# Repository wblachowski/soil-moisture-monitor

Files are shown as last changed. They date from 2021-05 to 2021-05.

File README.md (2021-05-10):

# Soil Moisture Monitor 🌱
> There's no reason to stick your finger in the dirt ever again.

This is an Arduino project for monitoring soil moisture to keep your plants lush and healthy. It comes with a standard moisture reading as well as automatic watering detection to let you know how long it's been since the last watering.

## Components
Originally, the project uses the following components (albeit many of these could be substituted with their counterparts without much effort):
* Arduino Nano
* LM393 Soil moisture sensor
* DS3231 RTC
* SSD1306 128x32 OLED Display

## Usage
The main aim of the monitor is to display the soil moisture to the user. However, there are a few add-ons to make the experience even better.

### Moisture sensing
The moisture is measured every minute by supplying the power to the sensor for 50ms and taking the measurement. The measurement in 0-100% format is then displayed in large font in the left part fo the display.

The reason for taking measurements at intervals instead of continuously is to slow down the sensor rusting (some rusting can't be prevented, sadly).

### Watering detection
The system measures the Exponential Moving Average of the sensor measurements and keeps track of the latest 30 values.
Based on some thresholds, the monitor detects whether a significant increase in the moisture has occurred.
Once watering is detected, the system saves the watering time in its non-volatile memory and, henceforth, displays the time that has passed since the last watering on the right-hand side of the display.
A new watering can't be detected until at least 3 hours since the last one.
This behaviour aims to prevent multiple watering events from being detected if the moisture level keeps raising for an extended period of time after the actual watering.

### Watering triggering
If the user feels uncertain about the automatic watering detection mechanism, they can let the system know that the watering has happened by pressing a special button and holding it for 2 seconds.
This event is treated in the same way as the automatic detection.

## Structure

* `main`

Contains arduino code.

* `pcb`

Contains designs for a printed circuit board, created in Autodesk EAGLE.

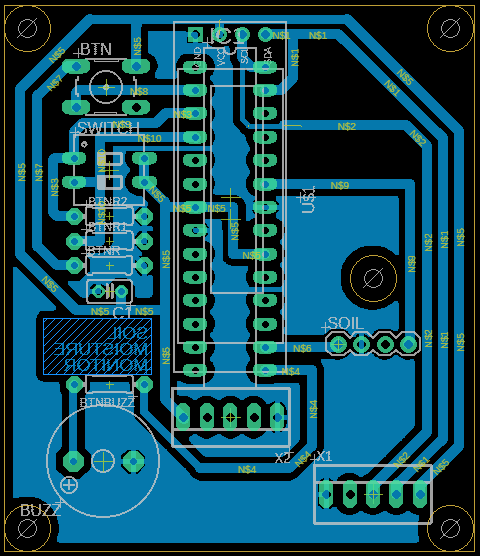
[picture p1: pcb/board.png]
pcb


* `case`

Contains the design of a 3D-printable case for the complete project. The case has snap joints and special cutouts for LCD, power supply, and moisture sensor connection.

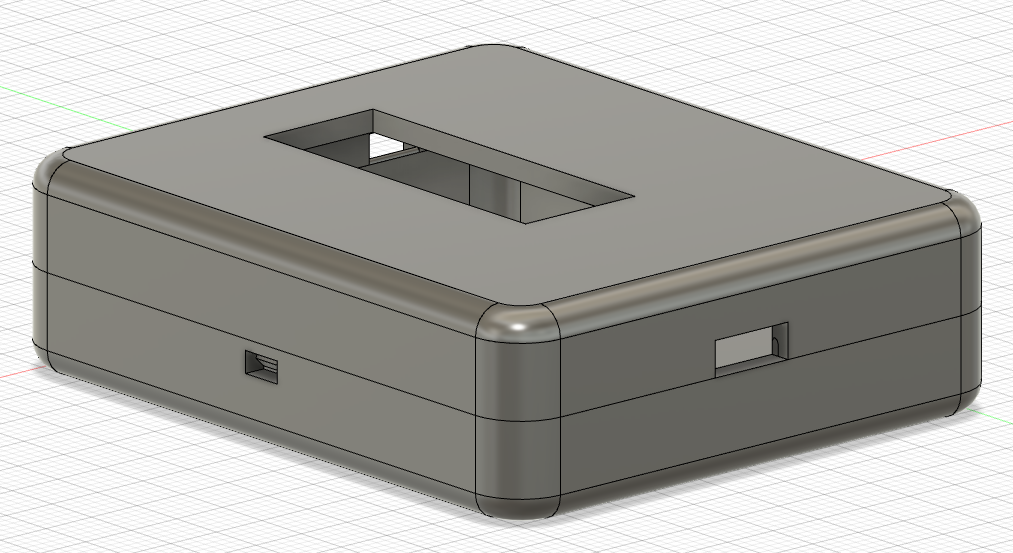
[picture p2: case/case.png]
case


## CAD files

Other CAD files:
case/Moisture monitor case.f3d

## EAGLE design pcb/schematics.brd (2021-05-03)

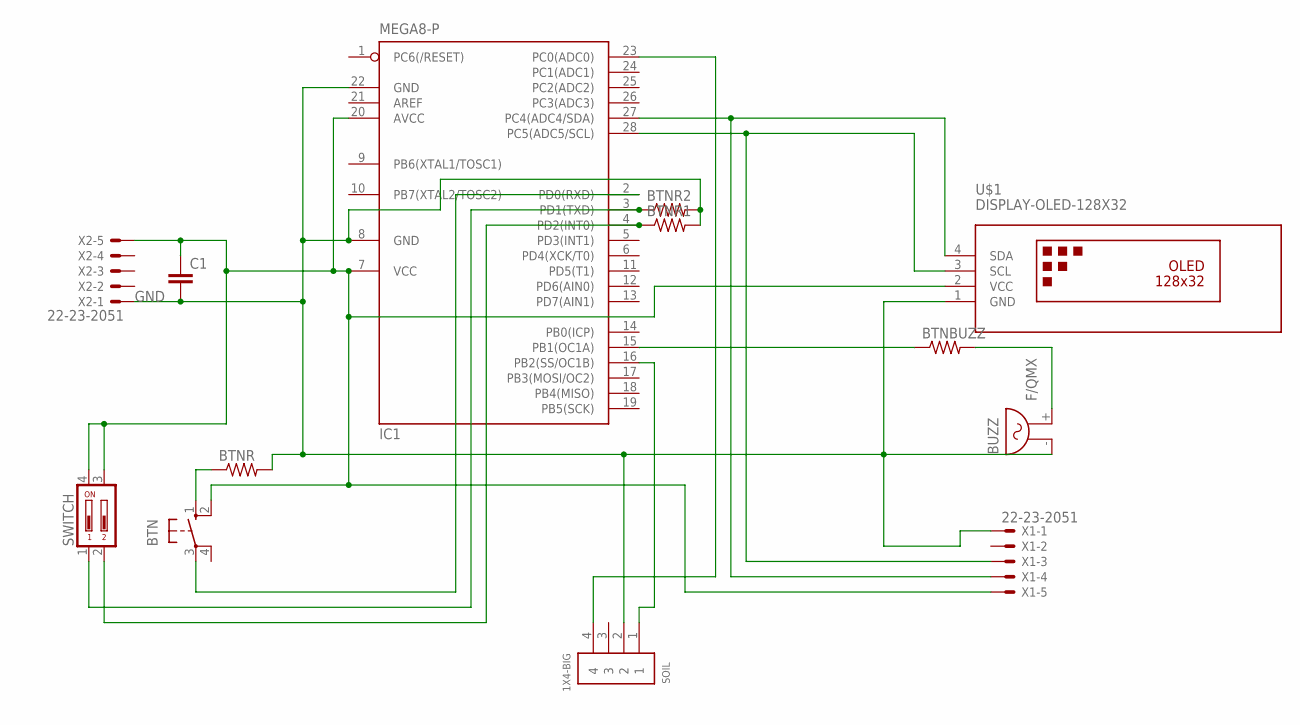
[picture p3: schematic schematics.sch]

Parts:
BTN: 10-XX; B3F-10XX
BTNBUZZ: R-US_0204/7; 0204/7
BTNR, BTNR1, BTNR2: R-US_0204/7; 0204/7
BUZZ: F/QMX
C1: C-EU025-025X050; C025-025X050
IC1: MEGA8-P; DIL28-3
SOIL: 1X4-BIG; 1X04-BIG
SWITCH: DIP02YL
U$1: DISPLAY-OLED-128X32
X1, X2: 22-23-2051

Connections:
GND: BTNR.2, BTNR1.2, BTNR2.2, BUZZ.- (1), C1.2, IC1.8 (GND), IC1.22 (GND), SOIL.2, U$1.1 (GND), X1.1, X2.1
unnamed: IC1.27 (PC4(ADC4/SDA)), U$1.4 (SDA), X1.4
unnamed: IC1.28 (PC5(ADC5/SCL)), U$1.3 (SCL), X1.3
unnamed: BTNR2.1, IC1.3 (PD1(TXD)), SWITCH.1
unnamed: BTNBUZZ.1, IC1.15 (PB1(OC1A))
unnamed: BTN.2 (S1), C1.1, IC1.7 (VCC), IC1.20 (AVCC), SWITCH.3, SWITCH.4, U$1.2 (VCC), X1.5, X2.5
unnamed: IC1.16 (PB2(SS/OC1B)), SOIL.1
unnamed: BTN.1 (S), BTNR.1
unnamed: BTN.3, IC1.2 (PD0(RXD))
unnamed: IC1.23 (PC0(ADC0)), SOIL.4
unnamed: BTNR1.1, IC1.4 (PD2(INT0)), SWITCH.2
unnamed: BTNBUZZ.2, BUZZ.+ (2)

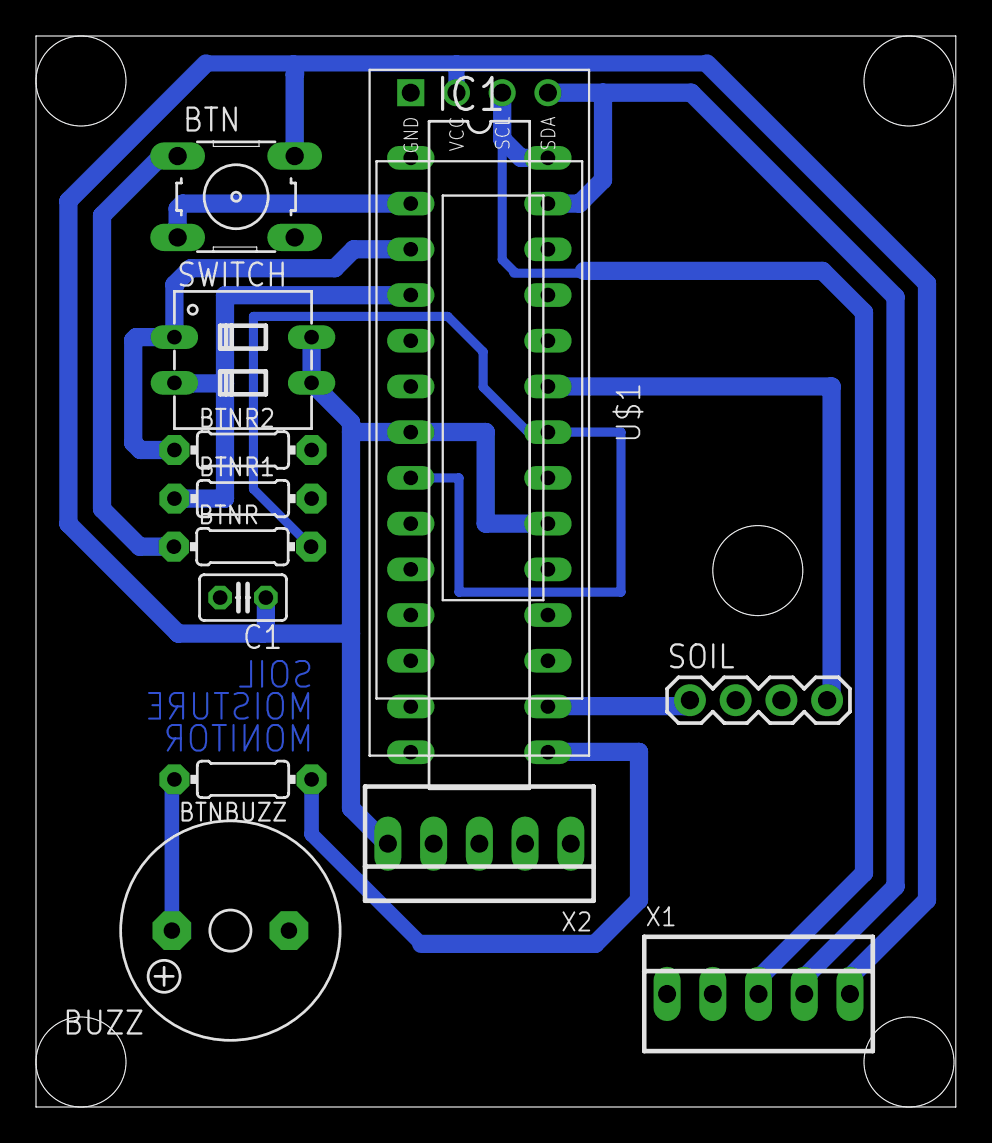
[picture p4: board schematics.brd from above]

Board: 2 copper layers, 51.1 x 59.5 mm, 13 parts (0 on the bottom side), 12 nets.

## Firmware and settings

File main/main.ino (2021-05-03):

#include <DS3231.h>
#include <CircularBuffer.h>
#include "Display.h"
#include "Memory.h"
#include "TimeGuard.h"
#include "ButtonHandler.h"

// Pinout:
#define MOISTURE_SENSOR A0
#define MOISTURE_POWER 10
#define BUZZER 9
#define BUTTON 0
#define DISPLAY_MODE 1
#define BUZZER_MODE 2

// Constants:
#define BUTTON_PRESS_DUR 2L * 1000      // Button has to be pressed for 2s
#define BUTTON_DEBOUNCE 30L             // Button has to be held for at least 30ms
#define MEASUREMENT_INTERVAL 60L * 1000 // Moisture measured every minute
#define MEASUREMENT_DUR 50L             // Moisture measured after powering the sensor for 50ms
#define BUZZER_DUR 50L                  // Buzz for 30ms after watering detection
#define CLOCK_INTERVAL 250L             // Displayed time updated every 250ms
#define HISTORY_EMA_BETA 0.9            // EMA with averaging over 10 measurements
#define WATERING_INTERVAL 3L * 60 * 60  // At least 3h since last watering to detect a new one
#define WATERING_INCREASE_THRESHOLD 5   // At least 5 percent increase to detect watering
#define WATERING_WINDOW 30              // Increase detection window
#define DISPLAY_MODE_INTERVAL 30L       // Display mode probed each 30 ms

Display display;
Memory memory;
RTClib myRTC;

TimeGuard measurementGuard(MEASUREMENT_INTERVAL);
TimeGuard clockGuard(CLOCK_INTERVAL);
TimeGuard displayModeGuard(DISPLAY_MODE_INTERVAL);

uint32_t lastWatering = 0L;
int lastDisplayRotation = 0;
int lastMoisture = 0;
CircularBuffer<int, WATERING_WINDOW> history;
ButtonHandler buttonHandler(BUTTON_DEBOUNCE);

void setup()
{
  pinMode(MOISTURE_POWER, OUTPUT);
  pinMode(BUZZER, OUTPUT);
  pinMode(BUTTON, INPUT);
  pinMode(DISPLAY_MODE, INPUT);
  pinMode(BUZZER_MODE, INPUT);
  lastDisplayRotation = digitalRead(DISPLAY_MODE);
  display.initialize(lastDisplayRotation);
  lastWatering = memory.readLastWatering();
  buzz();
}

void loop()
{
  unsigned long pressTime = buttonHandler.pressTime(digitalRead(BUTTON), millis());
  display.displayPressTime(((double)pressTime) / (BUTTON_PRESS_DUR));
  if (pressTime >= BUTTON_PRESS_DUR)
  {
    reactToWatering();
    buttonHandler.disableUntilChange();
  }
  if (displayModeGuard.execute(millis())){
    int displayRotation = digitalRead(DISPLAY_MODE);
    if (lastDisplayRotation != displayRotation){
       display.setRotation(displayRotation);
       display.displayTime(myRTC.now());
       display.displayLastWatering(myRTC.now().unixtime(), lastWatering);
       display.displayMoisture(lastMoisture);
       lastDisplayRotation = displayRotation;
    }
  }
  if (clockGuard.execute(millis()))
  {
    display.displayTime(myRTC.now());
  }
  if (measurementGuard.execute(millis()))
  {
    display.displayLastWatering(myRTC.now().unixtime(), lastWatering);
    lastMoisture = measureMoisture();
    display.displayMoisture(lastMoisture);
    int historyInput = calculateHistoryInput(lastMoisture);
    history.push(historyInput);
    if (wateringDetected())
    {
      reactToWatering();
    }
  }
}

int measureMoisture()
{
  analogWrite(MOISTURE_POWER, 255);
  delay(MEASUREMENT_DUR);
  int sensorValue = analogRead(MOISTURE_SENSOR);
  analogWrite(MOISTURE_POWER, 0);
  return convertToPercentage(sensorValue);
}

int convertToPercentage(int value)
{
  return map(value, 1023, 0, 0, 100);
}

int calculateHistoryInput(int moisture)
{
  if (history.isEmpty())
  {
    return moisture;
  }
  return history.last() * HISTORY_EMA_BETA + (1 - HISTORY_EMA_BETA) * moisture;
}

int wateringDetected()
{
  bool enoughData = history.isFull();
  bool wateringIntervalPassed = myRTC.now().unixtime() - lastWatering > WATERING_INTERVAL;
  bool moistureIncrease = history.last() - history.first() > WATERING_INCREASE_THRESHOLD;
  return enoughData && wateringIntervalPassed && moistureIncrease;
}

void reactToWatering()
{
  lastWatering = myRTC.now().unixtime();
  memory.saveLastWatering(lastWatering);
  display.displayLastWatering(myRTC.now().unixtime(), lastWatering);
  buzz();
}

void buzz()
{
  if(digitalRead(BUZZER_MODE)){
      tone(BUZZER, 3000, BUZZER_DUR);
  }
}

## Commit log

2021-02-08 Add powering the sensor once every minute
2021-02-12 Add rudimentary button handling
2021-02-12 Extract button related logic
2021-02-12 Add displaying button press time
2021-02-12 Add disabling button handler upon reaching the threshold
2021-02-12 Add watering on button press + refactor
2021-02-15 Add button debouncing
2021-02-15 Fix screen flicker on watering
    [main.ino]
2021-02-17 Change sensor (reverse logic)
    [main.ino]
2021-02-17 Add buzz on start
    [main.ino]
2021-03-02 Revert to the previous sensor
    [main.ino]
2021-03-08 Add buzz to watering reaction
    [main.ino]
2021-03-30 Add pcb files
    [schematics.brd, schematics.sch]
2021-03-31 Update pcb
    [schematics.sch]
2021-04-13 Update eagle files
    [schematics.brd, schematics.sch]
2021-04-14 Update eagle files (shrinking the board)
    [schematics.brd]
2021-04-14 Change button pin
2021-04-14 Add slide switch
    [schematics.brd, schematics.sch]
2021-04-19 Update pcb schematics to its final form
2021-05-03 Upadate pcb to use passive buzzer
    [schematics.brd, schematics.sch]
2021-05-03 Change buzzer to pasive
    [main.ino]
2021-05-10 Add image of the board
2021-05-10 Add case files
    [Moisture monitor case.f3d]

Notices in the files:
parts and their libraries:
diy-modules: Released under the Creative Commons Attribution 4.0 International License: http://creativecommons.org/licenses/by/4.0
